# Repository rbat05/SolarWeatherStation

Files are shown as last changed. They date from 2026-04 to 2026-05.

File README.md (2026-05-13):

# SolarWeatherStation
An end-to-end, off-grid IoT environmental telemetry system featuring custom hardware, low-power RF bridging, and a retro LCD-themed web dashboard.









<p align="center">
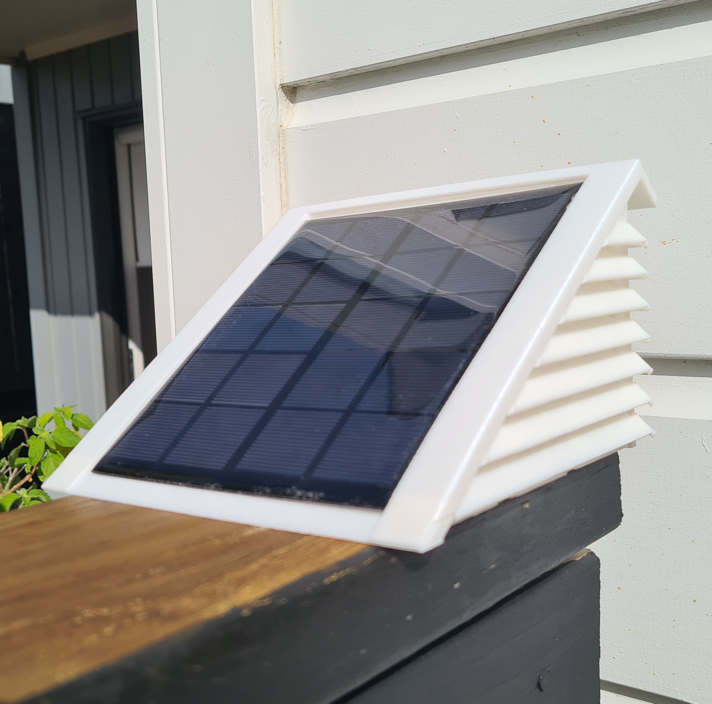
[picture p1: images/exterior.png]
Solar Weather Station Exterior
  
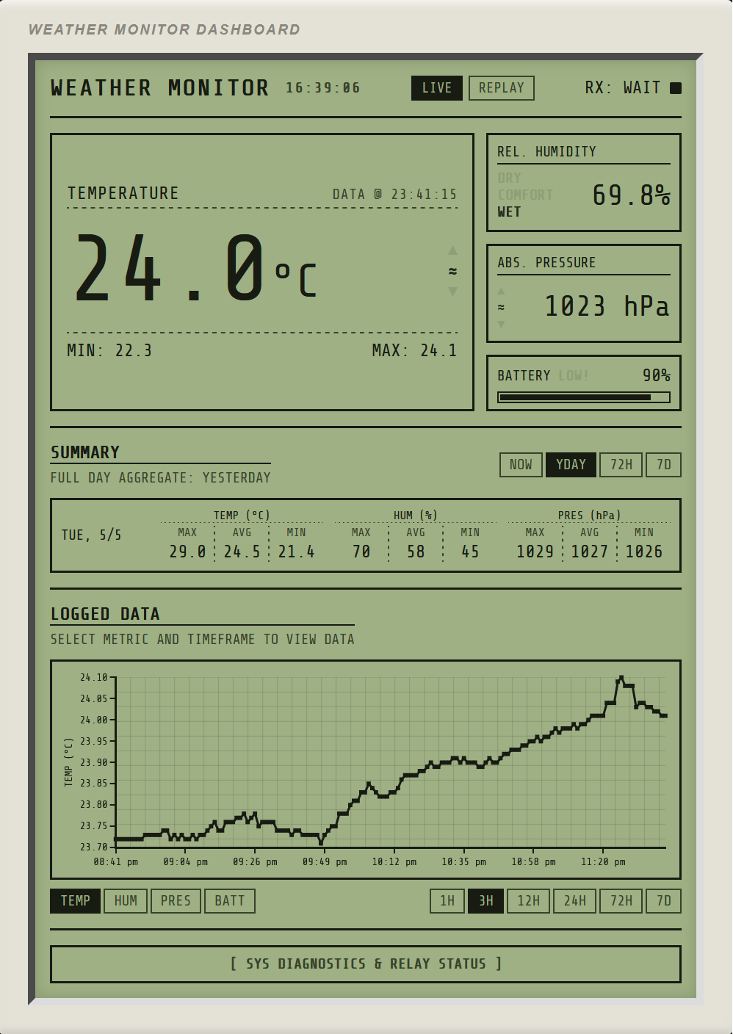
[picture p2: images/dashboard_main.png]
Solar Weather Station Dashboard
  <br>
  <em>Solar Weather Station Exterior (left) and Dashboard (right)</em>
</p>

## Table of Contents

1. [Overview](#overview)
2. [Features](#features)
3. [Performance](#performance)
4. [Design Showcase](#design-showcase)
5. [Bill of Materials](#bill-of-materials)
6. [System Architecture](#system-architecture)
7. [Firmware & Code](#firmware--code)
8. [3D-Printed Parts](#3d-printed-parts)
9. [License](#license)

---

## 1. Overview
The **Solar Weather Station** is a completely custom-engineered, three-tier IoT ecosystem designed to capture, transmit, and visualize highly accurate micro-climate data. 

>Currently measures **temperature**, **humidity**, **absolute pressure**, and **battery voltage** at 30 seconds intervals.

Operating entirely off-grid, the remote sensor node utilizes solar power and aggressive deep-sleep optimizations to monitor environmental conditions indefinitely. To bypass the extreme battery drain of standard WiFi, it broadcasts lightweight packets via ESP-NOW to a continuously powered indoor Relay node. This Relay acts as a bridge, forwarding the data into a local Python Flask server where it is logged, archived, and displayed on a visually striking, retro-commercial LCD-style dashboard.

## 2. Features
* **100% Off-Grid Operation:** Powered by a localized solar charging circuit and Li-Po battery.
* **Decoupled RF Architecture:** Uses a low-latency, low-power ESP-NOW to WiFi bridge, saving massive amounts of battery life compared to direct-to-router connections.
* **Bulletproof Failsafes:** Features hardware brownout bypassing, local SD card data logging, offline memory buffering (RTC memory), and relay rate-limited backfilling so data is never lost during network dropouts.
* **Retro LCD Dashboard:** A beautiful, responsive, bespoke green-and-black dot-matrix web interface built with pure HTML/JS, Flask, and SQLite.
* **Historical Replay Engine:** A dual-database architecture allows you to dynamically load archived CSV data into a sandbox database to "replay" historical weather events on the dashboard without interrupting the live data stream.
* **Local vs. Regional Analytics:** Automatically fetches regional telemetry from the Open-Meteo API to compare your micro-climate directly against metropolitan averages.

## 3. Performance
Aggressive power-saving techniques were implemented in the ESP32 C++ firmware. By throttling the clock speed down to 80MHz, actively forcing the WiFi/Bluetooth modems off during boot initialization, and removing parasitic hardware LEDs (like the one on the DS3231 RTC), the remote station achieves incredible efficiency:

* **Average Active Time:** < 8.0 seconds per wake cycle.
* **Average Active Current:** ~60 mA (Peak during SD Write & ESP-NOW transmission).
* **Average Sleep Current:** ~2.5 mA.
* **Weighted Average Draw:** ~4.03 mA over a standard cycle.

This ultra-low consumption allows the station to easily survive extended periods of heavy cloud cover without dropping below critical battery voltages.

## 4. Design Showcase

- **Mechanical Design:** Custom 3D-printed Stevenson Screen with integrated mounting points for the PCB and solar panel. The solar panel sits at a 35-degree angle to maximize sun exposure (in Auckland, NZ) while the louvers provide airflow to ensure accurate sensor readings.
  <p align="center">
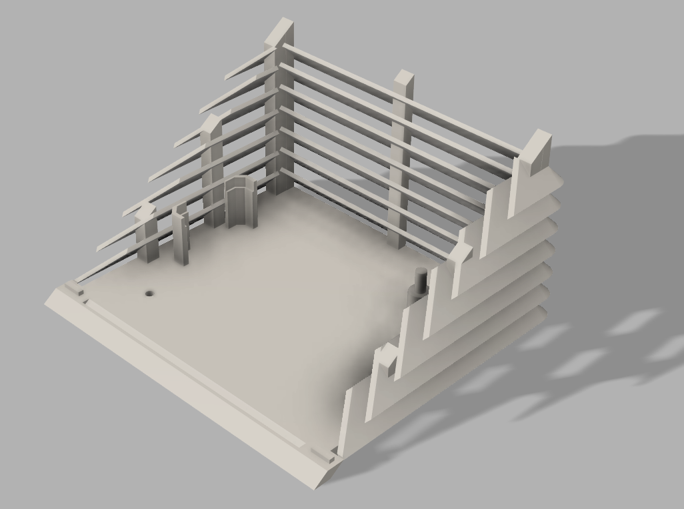
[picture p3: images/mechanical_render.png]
Mechanical Render
    <br>
    <em>3D-Printed Stevenson Screen Render</em>
  </p>

- **Internal Assembly:** Custom PCB secured inside the Stevenson Screen.
  <p align="center">
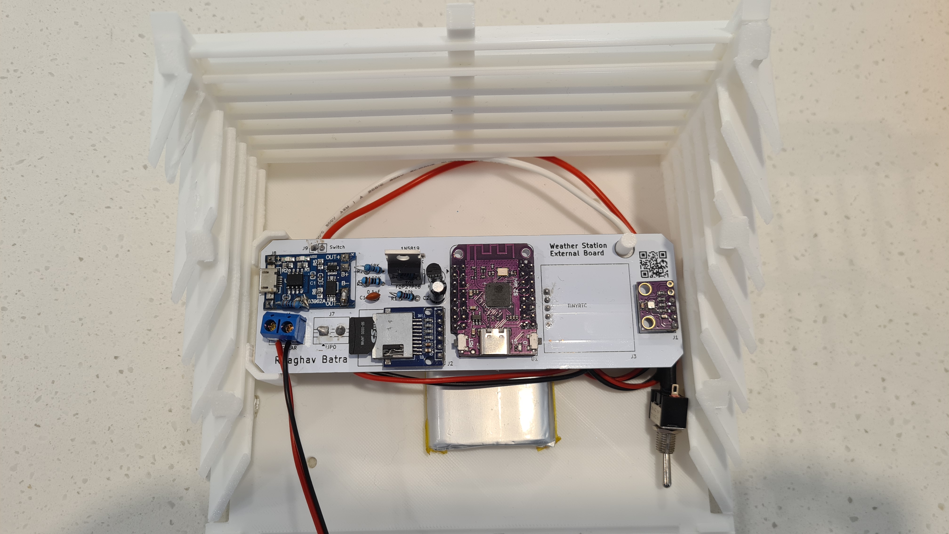
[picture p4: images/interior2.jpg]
Solar Weather Station Interior
    <br>
    <em>Custom PCB Mounted Inside Enclosure</em>
  </p>

- **LCD Dashboard:** A retro-inspired web interface displaying real-time and historical weather data.

**Dashboard Features:**

- **Live Mode:** Continuously streams real-time environmental data directly from the local SQLite database.
  <p align="center">
    Dashboard Main View (Live Mode)<br>
    <em>Main Dashboard View (Live Mode)</em>
  </p>

- **Historical Replay Engine:** Dynamically loads archived 7-day CSV files into a sandbox database to replay historical weather events without interrupting live data ingestion. Can set custom timeframes to analyze specific events (e.g., a storm).
  <p align="center">
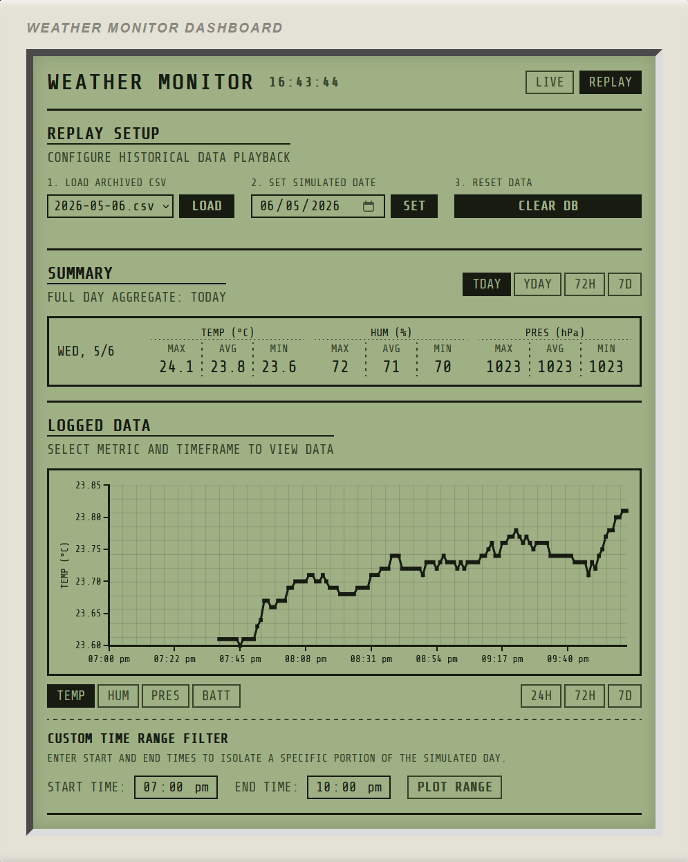
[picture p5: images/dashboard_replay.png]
Dashboard Replay Mode
    <br>
    <em>Replaying Historical Sandbox Data</em>
  </p>

- **Local vs. Regional Comparison:** Automatically polls regional telemetry from the Open-Meteo API to compare your micro-climate directly against metropolitan averages (displayed alongside the "Today" summary).
  <p align="center">
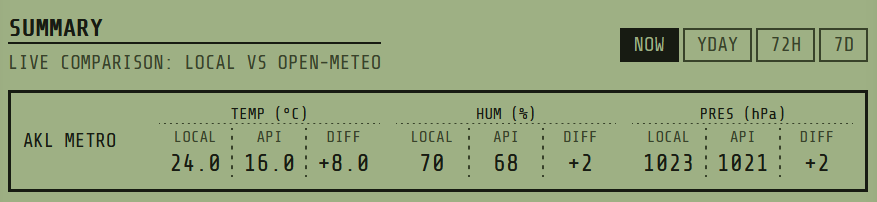
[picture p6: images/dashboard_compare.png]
Dashboard Regional Compare
    <br>
    <em>Local Micro-climate vs. Regional Averages</em>
  </p>

- **Summary Statistics:** Provides actionable insights and rolling statistics (High, Low, Average) across different timeframes:
  - **Today:** Current day metrics.
  - **Yesterday:** A rolling 24-hour window to spot diurnal patterns.
  - **72 Hours & 7 Days:** Extended views to analyze multi-day weather events and trends.

- **Interactive Graphing:** Powered by Chart.js, the interactive graph can map individual metrics over adjustable time-scales (1 hour, 3 hours, 12 hours, 24 hours, 72 hours, or 7 days):
  - **Temperature**
  - **Humidity**
  - **Absolute Pressure**
  - **Battery Voltage**
  <p align="center">
    Dashboard 7-Day Graph<br>
    <em>Interactive 7-Day Telemetry Chart</em>
  </p>

## 5. Bill of Materials
### Remote Weather Station
* **Microcontroller:** ESP32 (Throttled to 80MHz)
* **Environmental Sensor:** BME280 (Temperature, Humidity, Absolute Pressure)
* **Real-Time Clock:** DS3231 (Hardware power LED physically removed for power savings)
* **Storage:** MicroSD Card Module (SPI)
* **Power:** Solar Panel, TP4056 (or equivalent) Charge Controller, 3.7v Li-Po/18650 Battery

### Indoor Relay Node
* **Microcontroller:** ESP8266

### Local Server
* **Hardware:** Any local machine (e.g., Raspberry Pi) capable of running Python 3.

## 6. System Architecture
The system is broken into three distinct operational layers:

1. **Layer 1: Edge Telemetry (Weather Station)** 
   Wakes up on an interval timer, samples the BME280 and battery voltage, writes to the local SD card, and fires a rapid ESP-NOW string to the Relay before returning to deep sleep. For a detailed breakdown, see the [Weather Station README](./code/WeatherStationCode/README.md).
2. **Layer 2: Network Bridge (Relay Node)** 
   Stays awake permanently on mains power. Listens for the ESP-NOW MAC address. Upon receiving a packet, it formats it into a JSON payload and executes an HTTP POST request over the home WiFi network. For a detailed breakdown, see the [Relay Node README](./code/RelayCode/README.md).
3. **Layer 3: Data Ingestion & Visualization (Dashboard)** 
   A Python Flask server operating on a local machine. It intercepts the HTTP POST at the `/ingest` endpoint, commits the data to an SQLite database, handles infinite 7-day auto-archiving to CSV, and serves the UI. For a detailed breakdown, see the [Dashboard README](./code/DashboardCode/README.md).

## 7. Firmware & Code
The codebase is heavily modularized across three main directories. Please refer to their individual `README.md` files for deep dives into their logic.

* **`/code/WeatherStationCode`:** 
  C++ (PlatformIO) for the remote ESP32. Handles aggressive power management, hardware watchdog failsafes, I2C/SPI bus management, and RTC memory buffering.
* **`/code/RelayCode`:** 
  C++ (PlatformIO) for the indoor ESP8266. Features a non-blocking `millis()` architecture, in-memory offline packet buffering, auto-WiFi reconnections, and OTA flashing support.
* **`/code/DashboardCode`:** 
  Python/Flask backend and HTML/JS frontend. Handles the API endpoints, Open-Meteo polling, database querying, and the retro Chart.js interactive graph rendering.

## 8. Custom Hardware Integration
### Custom PCB (`/pcb`)
Rather than relying on messy jumper wires and breadboards, the Weather Station relies on a completely custom-designed Printed Circuit Board. This custom PCB integrates the ESP32, charge controllers, and sensor headers into a single, reliable footprint. This minimizes point-of-failure wire disconnects, reduces electrical noise on the I2C/SPI busses, and provides a perfectly dimensioned mounting solution for the 3D-printed case. Designed using KiCAD 10.

### 3D-Printed Parts (`/cad`)
All physical enclosures for the project were custom modeled in CAD to fit the bespoke electronics and withstand the elements.

* **Stevenson Screen (Weather Station):** 
  A classic multi-louvered meteorological enclosure. It is specifically designed to shield the BME280 sensor from direct UV radiation and precipitation while allowing ambient wind/air to freely pass through. This prevents artificial greenhouse heating inside the case, ensuring the temperature readings are a true reflection of the outside air. Provided a .step file for easy modification of the full assembly in any CAD software.
* **Low-Profile Relay Case:** 
  This enclosure can be found at [Makerworld](https://makerworld.com/en/models/58547-nodemcu-v2-cp2102-cover#profileId-60347). Credit to Lyron for the original design. A hole was cut on the top for the heatsink.

## 9. License
This project is licensed under the GNU General Public License v3.0 (GPL-3.0).

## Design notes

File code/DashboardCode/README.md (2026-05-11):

# Solar Weather Station - Dashboard

## Overview
The Dashboard code provides a visually striking, Retro Commercial LCD-themed web interface and a robust Python Flask backend to serve as the central hub for your Solar Weather Station. It receives incoming telemetry via HTTP POST, stores the data locally in an SQLite database, archives historical readings, and presents everything in a highly interactive, at-a-glance format.

## Features & Functions
*   **Flask Web Server & API:** Listens on `/ingest` for JSON or CSV formatted POST requests sent by the Relay node, validating and parsing the payload.
*   **Dual-Database Architecture:** Maintains a `weather.db` for live operational data and a separate `replay.db` for isolated historical analysis, ensuring the live data stream is never interrupted.
*   **Auto-Archival System:** Automatically prunes live database entries older than 7 days to prevent bloat, appending all raw incoming data to permanent daily `.csv` files inside the `archive` directory.
*   **External API Integration:** Fetches comparative weather metrics in real-time from the Open-Meteo API (Auckland Metro) to provide a local vs. regional analysis.

## Code Outcome
A complete, self-hosted web dashboard that requires no external cloud services to operate. It provides deep analytical tools for micro-climate data while maintaining a uniquely stylized, immersive user experience.

## Usability & Dashboard Interface

The dashboard is designed entirely around an aesthetic "Commercial Dot-Matrix LCD" theme. It prioritizes clarity, high contrast, and at-a-glance readability using a bespoke green-and-black color palette.

### Operational Modes
*   **LIVE Mode:** The default, real-time state. The dashboard automatically polls the backend every 5 seconds, pulling the absolute latest data. The UI displays real-time health badges (`RX: OK` or `RX: WAIT`) and updates the hero readouts instantaneously when the relay pushes a new packet.
*   **REPLAY Mode:** A powerful historical analysis tool. The user can select any archived `.csv` file from a dropdown, load it into the temporary replay database, and set a simulated date. The entire dashboard behaves as if that historical day is currently happening, allowing for deep-dive investigations into past weather events using a Custom Time Range filter.

### Displayed Metrics & Readouts
*   **Hero Readouts:**
    *   **Temperature (°C):** Features a massive digital readout with trend indicators (▲/≈/▼) showing if the temperature is rising, falling, or stable compared to the last hour. Includes daily Min/Max values.
    *   **Relative Humidity (%):** Includes visual segment thresholds indicating whether the air is `DRY` (<40%), `COMFORT` (40%-60%), or `WET` (>60%).
    *   **Absolute Pressure (hPa):** Monitors barometric pressure with rapid change indicators to help predict incoming weather fronts.
    *   **Battery Level (%):** A visual fill-bar representing the remote solar station's Li-Po battery charge, including a flashing `LOW!` warning segment if it drops below 20%.

### Interactive Charting
Powered by Chart.js, the main graph renders a strict dot-matrix style line chart (using straight lines and square points) with an animated radar-sweep effect sweeping across the canvas.
*   **Timeframes:** Users can pivot between 1H, 3H, 12H, 24H, 72H, and 7D views.
*   **Dynamic Gap Visualization:** If the weather station goes offline, the chart mathematically detects the missing time buckets. Instead of connecting unrelated data points, it seamlessly breaks the solid line, rendering a transparent, dashed "gap" line so the user knows exactly when data was lost.

### Summaries & Diagnostics
*   **Live Comparison:** The summary panel displays a side-by-side table comparing the local station's data directly against the regional Open-Meteo API, calculating the exact numerical difference.
*   **Aggregate Data:** Users can tab through yesterday, the last 3 days, and the last 7 days to view automatically calculated Highs, Lows, and Averages across all metrics.
*   **System Diagnostics Panel:** A collapsible menu dedicated to hardware health. It displays the timestamp of the last contact, raw payload strings, HTTP response codes, total packets received, and a calculated Packet Loss percentage.

### Deploy Folder
Inside the `deploy` folder, there is a static version of the dashboard that is used to showcase basic capabilties. To run this, change directory into the folder and start a simple HTTP server:
```bash
cd deploy
python3 -m http.server 8000
```
Then navigate to `http://localhost:8000` in your web browser to view the static dashboard.

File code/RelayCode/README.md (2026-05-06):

# Solar Weather Station - Relay Node

## Overview
The Relay code acts as the crucial bridge between the remote, low-power Weather Station and the centralized Server/Dashboard. Running on an ESP8266, it sits within the range of both the station's low-power radio (ESP-NOW) and the home's high-power WiFi network.

## Features & Functions
*   **Continuous Listening:** Operates completely awake, utilizing ESP-NOW to constantly listen for incoming, transient data packets broadcasted by the remote weather station.
*   **WiFi Forwarding:** Establishes and maintains a connection to the local WiFi network, taking the incoming ESP-NOW string and forwarding it to the Dashboard's `/ingest` API endpoint via HTTP POST requests.
*   **Health Dashboard Server:** Hosts a lightweight web server on port 80 displaying real-time diagnostics, including uptime, WiFi RSSI, rolling packet loss percentage, and offline buffer status.
*   **Over-The-Air (OTA) Updates:** Supports wireless flashing, allowing you to update the relay's firmware remotely without needing to physically disconnect it.

## Code Outcome
By decoupling the remote station from the local WiFi network, the Relay allows the station to save massive amounts of battery. The Relay guarantees data packets are successfully transitioned from off-grid radio signals to standard web traffic.

## Hardware & Software Safety Features
Because the Relay serves as a single point of failure for data ingestion, it includes robust fault-tolerance mechanisms:

1.  **Offline Buffering:** If the home WiFi drops or the backend Flask server restarts, the Relay does not discard incoming data. It stores up to 100 missed packets in an in-memory string array buffer.
2.  **Rate-Limited Backfill:** Once the server connection is re-established, the Relay pushes the buffered backlog using a rate-limited retry interval (e.g., 5 seconds) to prevent overwhelming the server with a massive burst of HTTP requests.
3.  **Non-Blocking Architecture:** Uses `millis()`-based timing instead of `delay()` for all primary loop operations. This ensures that a stalled HTTP request or a slow WiFi reconnection attempt never blocks the ESP-NOW callback, guaranteeing it never misses a radio packet from the outdoor station.
4.  **Auto-Reconnection:** Built-in WiFi fallback routines automatically negotiate reconnections if the primary network drops out.

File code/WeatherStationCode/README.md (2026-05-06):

# Solar Weather Station - Remote Node

## Overview
The Weather Station code powers the remote, solar-charged ESP32 microcontroller unit responsible for capturing local environmental telemetry. Its primary goal is to operate entirely off-grid, efficiently managing its own power reserves while providing highly accurate, continuous weather data via a BME280 sensor, DS3231 RTC, and local SD card storage.

## Features & Functions
*   **Environmental Telemetry:** Interfaces with a BME280 sensor via custom I2C pins (SDA: 33, SCL: 35) to capture Temperature, Relative Humidity, and Absolute Pressure. The sensor is kept in a low-power "sleep mode" and briefly awoken into "forced mode" just long enough to capture a reading.
*   **Aggressive Power Management:** The ESP32's clock speed is heavily throttled down from 240MHz to 80MHz, and the WiFi/Bluetooth modems are actively forced asleep during boot (`esp32ModemSleep()`) to aggressively shave off milli-amps during the active cycle.
*   **Deep Sleep Cycling:** To conserve battery, the station wakes up every 30 seconds, takes rapid readings, writes to the SD card, transmits the data packet via ESP-NOW, and immediately returns to a low-power deep sleep state. Active time is kept to an absolute minimum (under 8 seconds).
*   **Local SD Card Archival:** Every reading is appended to a local CSV file on an SD card via a custom SPI bus (SCK: 7, MISO: 9, MOSI: 11, CS: 12). If wireless transmission fails, the physical data is completely secure.
*   **RTC Memory Buffering:** The code utilizes the ESP32's `RTC_DATA_ATTR` memory to maintain an offline buffer of up to 10 readings across deep sleep cycles. If the Relay node is unreachable, the station stores the readings and bulk-sends the backlog (oldest first) on the next successful connection.

## Code Outcome
A highly resilient, "deploy-and-forget" weather node that can run indefinitely on solar power, constantly delivering localized weather patterns without human intervention.

## Hardware & Software Safety Features
Because this node is deployed remotely and exposed to the elements, several safety mechanisms have been implemented in the code:

1.  **Manual Brownout Override:** Standard ESP32 hardware brownout detection can sometimes trigger false-positive boot loops on solar setups when the voltage slightly dips during radio spikes. The code intentionally bypasses the internal hardware check (`WRITE_PERI_REG(RTC_CNTL_BROWN_OUT_REG, 0)`) to ensure the board successfully boots and delegates battery management directly to the firmware logic.
2.  **Infinite Loop Safety Catch:** A failsafe `loopCounter` mechanism exists in the main `loop()` function. Because the execution is entirely handled sequentially in `setup()`, if the main loop accidentally iterates more than 1,000 times, the code mathematically determines the microcontroller is hung/frozen and forcefully throws it back into deep sleep to prevent battery drain.
3.  **Offline Resilience:** The combination of local SD storage and the 10-packet `RTC_DATA_ATTR` buffer ensures that brief networking dropouts, relay reboots, or WiFi outages do not result in permanent data loss. 
4.  **Visual Debugging:** Pin 15 provides physical LED flashes upon boot initialization and successful cycle completion, allowing for on-site visual confirmation of the unit's health without connecting it to a computer.

## Power Consumption & Hardware Notes
Based on a typical solar-assisted Li-Po setup, the system is highly optimized:
*   **Average Active Current:** ~60 mA (including SD write and ESP-NOW WiFi spikes).
*   **Average Sleep Current:** ~2.5 mA.
*   **Weighted Draw:** ~4.03 mA average over a cycle.

**⚠️ CRITICAL HARDWARE WARNING:** 
The DS3231 RTC module contains a surface-mounted power LED. Because the DS3231 is kept constantly powered, this LED single-handedly draws almost as much current as the sleeping ESP32! To achieve proper multi-month battery life, the power LED on the DS3231 breakout board *must* be physically desoldered or destroyed.

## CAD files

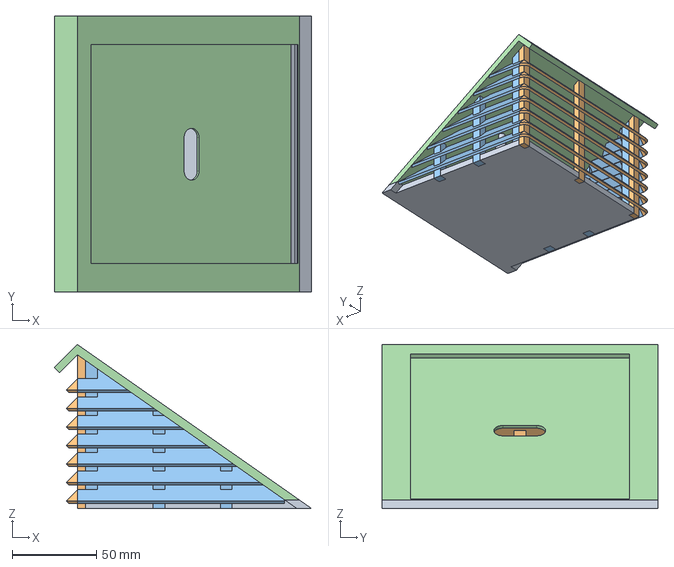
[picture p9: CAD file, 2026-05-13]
cad/external_unit_mini.step
152.9 x 164.0 x 97.5 mm

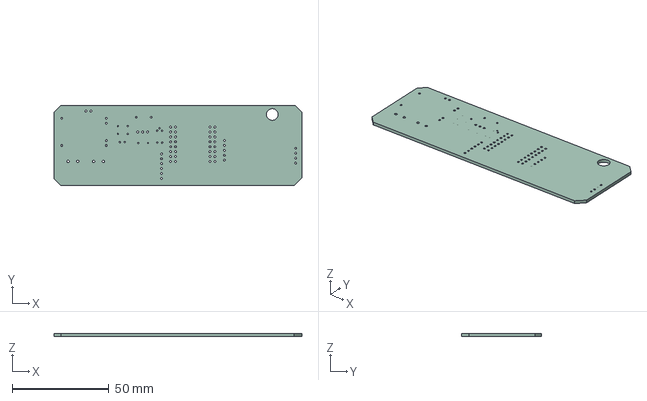
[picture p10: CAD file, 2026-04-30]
pcb/weather_station_ext/pcb.step
128.0 x 41.5 x 1.51 mm

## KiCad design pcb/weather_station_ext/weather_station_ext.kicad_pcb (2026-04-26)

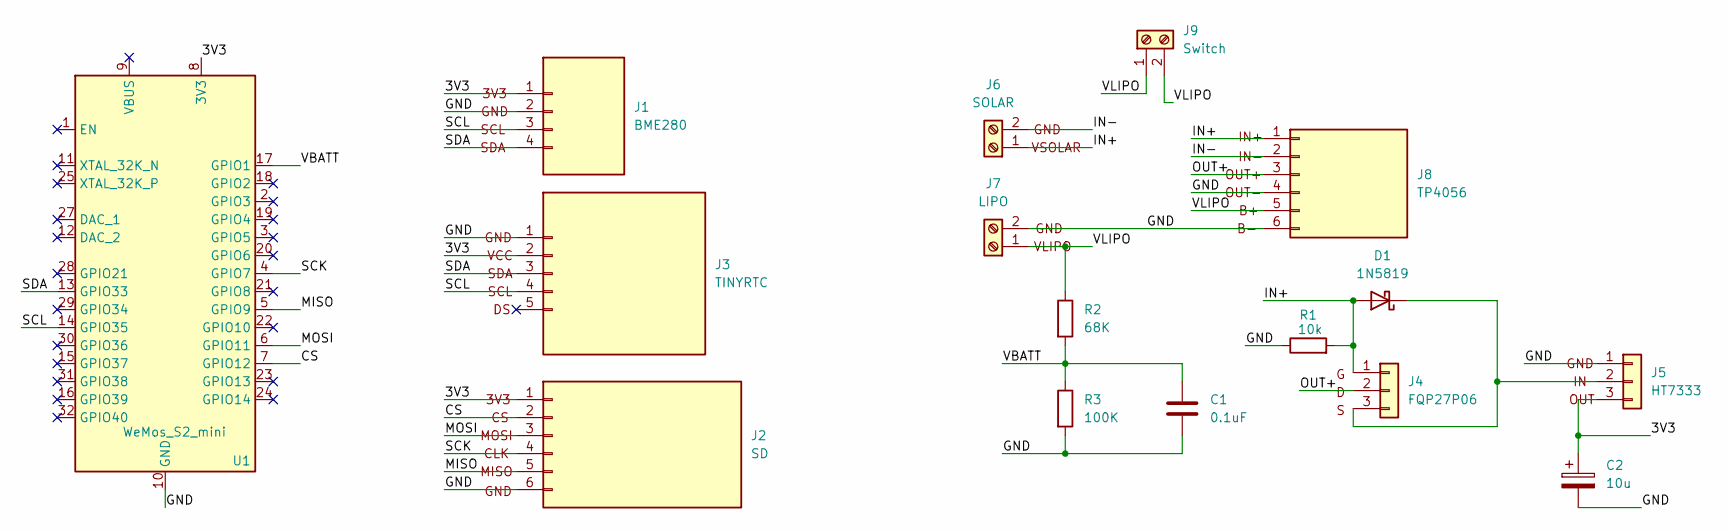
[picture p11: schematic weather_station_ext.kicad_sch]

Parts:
C1: 0.1uF; C_Disc_D3.0mm_W1.6mm_P2.50mm
C2: 10u; C_Disc_D3.0mm_W1.6mm_P2.50mm
D1: 1N5819; D_A-405_P7.62mm_Horizontal
J1: BME280; PinSocket_1x04_P2.54mm_Vertical
J2: SD; PinSocket_1x06_P2.54mm_Vertical
J3: TINYRTC; PinSocket_1x05_P2.54mm_Vertical
J4: FQP27P06; TO-220-3_Vertical
J5: HT7333; TO-92
J6: SOLAR; TerminalBlock_MaiXu_MX126-5.0-02P_1x02_P5.00mm
J7: LIPO; TerminalBlock_MaiXu_MX126-5.0-02P_1x02_P5.00mm
J8: TP4056; PinHeader_1x06_P2.54mm_Vertical
J9: Switch; PinHeader_1x02_P2.54mm_Vertical
R1: 10k; R_Axial_DIN0204_L3.6mm_D1.6mm_P5.08mm_Vertical
R2: 68K; R_Axial_DIN0204_L3.6mm_D1.6mm_P5.08mm_Vertical
R3: 100K; R_Axial_DIN0204_L3.6mm_D1.6mm_P5.08mm_Vertical
U1: WeMos_S2_mini; wemoss2

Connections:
/3V3: C2.1, J1.1 (3V3), J2.1 (3V3), J3.2 (3V3), J5.3 (OUT), U1.8 (3V3)
/CS: J2.2 (CS), U1.7 (GPIO12)
/GND: C1.2, C2.2, J1.2 (GND), J2.6 (GND), J3.1 (GND), J5.1 (GND), J7.2 (GND), J8.4 (OUT-), J8.6 (B-), R1.1, R3.2, U1.10 (GND), U1.26 (GND)
/IN+: D1.2 (A), J4.1 (GATE), J6.1 (VSOLAR), J8.1 (IN+), R1.2
/IN-: J6.2 (GND), J8.2 (IN-)
/MISO: J2.5 (MISO), U1.5 (GPIO9)
/MOSI: J2.3 (MOSI), U1.6 (GPIO11)
/OUT+: J4.2 (DRAIN), J8.3 (OUT+)
/SCK: J2.4 (CLK), U1.4 (GPIO7)
/SCL: J1.3 (SCL), J3.4 (SCL), U1.14 (GPIO35)
/SDA: J1.4 (SDA), J3.3 (SDA), U1.13 (GPIO33)
/VBATT: C1.1, R2.2, R3.1, U1.17 (GPIO1)
/VLIPO: J7.1 (VLIPO), J8.5 (B+), J9.1 (VLIPO), J9.2 (VLIPO), R2.1
unnamed: D1.1 (K), J4.3 (SOURCE), J5.2 (IN)

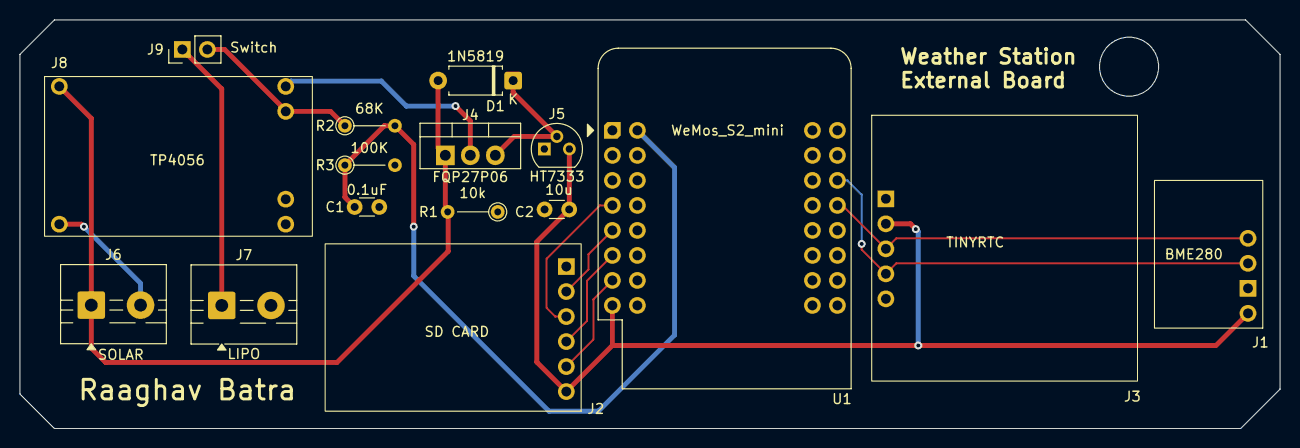
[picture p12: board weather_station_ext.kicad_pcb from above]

Board: 2 copper layers, 128.0 x 41.5 mm, 16 parts (0 on the bottom side), 14 nets.

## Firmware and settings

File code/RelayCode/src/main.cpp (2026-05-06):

#include <Arduino.h>
#include <ArduinoOTA.h>
#include <ESP8266HTTPClient.h>
#include <ESP8266WebServer.h>
#include <ESP8266WiFi.h>
#include <WiFiClient.h>
#include <espnow.h>
#include <user_interface.h>

#include "config.hpp"

volatile bool dataReceived = false;
String incomingDataString = "";

// Health Server & Buffer Variables
ESP8266WebServer server(80);
const int MAX_BUFFER_SIZE = 100;
String offlineBuffer[MAX_BUFFER_SIZE];
int bufferCount = 0;

unsigned long packetsReceived = 0;
int lastHttpResponse = 0;
unsigned long lastPostAttempt = 0;
unsigned long firstPacketTime = 0;
bool firstPacketReceived = false;
const unsigned long POST_RETRY_INTERVAL = 5000;

// --- UPDATE WITH YOUR COMPUTER IP ---
const char* serverName =
    "http://192.168.68.63:5000/ingest";  // Replaced /api/weather with /ingest

void handleRoot() {
  String html = "<!DOCTYPE html><html><head><title>Relay Health</title>";
  html +=
      "<meta name=\"viewport\" content=\"width=device-width, "
      "initial-scale=1\">";
  html +=
      "<style>body{font-family:Arial; margin:2rem; background-color:#121212; "
      "color:#ffffff;}";
  html +=
      ".stat{font-size:1.2rem; margin-bottom:10px; padding:10px; "
      "background:#1e1e1e; border-radius:5px;}</style></head><body>";
  html += "<h1>Weather Station Relay Health OTA TEST</h1>";

  unsigned long uptimeSeconds = millis() / 1000;
  int days = uptimeSeconds / 86400;
  int hours = (uptimeSeconds % 86400) / 3600;
  int mins = (uptimeSeconds % 3600) / 60;
  int secs = uptimeSeconds % 60;

  html += "<div class=\"stat\"><b>Uptime:</b> " + String(days) + "d " +
          String(hours) + "h " + String(mins) + "m " + String(secs) + "s</div>";
  html += "<div class=\"stat\"><b>WiFi RSSI:</b> " + String(WiFi.RSSI()) +
          " dBm</div>";
  html += "<div class=\"stat\"><b>WiFi Channel:</b> " + String(WiFi.channel()) +
          "</div>";
  html += "<div class=\"stat\"><b>ESP-NOW Packets Received:</b> " +
          String(packetsReceived) + "</div>";

  String lossStr = "--";
  if (firstPacketReceived) {
    unsigned long elapsedSec = (millis() - firstPacketTime) / 1000;
    unsigned long expected = (elapsedSec / 30) + 1;
    float loss = 100.0 * (1.0 - ((float)packetsReceived / expected));
    if (loss < 0) loss = 0;
    lossStr = String(loss, 1) + "% (" + String(expected) + " expected)";
  }
  html +=
      "<div class=\"stat\"><b>Rolling Packet Loss:</b> " + lossStr + "</div>";

  html += "<div class=\"stat\"><b>Latest ESP-NOW Packet:</b> " +
          (incomingDataString == "" ? "None" : incomingDataString) + "</div>";
  html += "<div class=\"stat\"><b>Last HTTP Response Code:</b> " +
          String(lastHttpResponse) + "</div>";
  html += "<div class=\"stat\"><b>Offline Buffer Status:</b> " +
          String(bufferCount) + " / " + String(MAX_BUFFER_SIZE) + "</div>";

  html += "</body></html>";
  server.send(200, "text/html", html);
}

// Callback function that will be executed when data is received
void onDataReceived(uint8_t* senderMac, uint8_t* incomingData, uint8_t len) {
  // Write the incoming data to the uint8_t array
  uint8_t recieved[len + 1];

  Serial.print("Received: ");

  for (int i = 0; i < len; i++) {
    Serial.print((char)incomingData[i]);
    recieved[i] = incomingData[i];
  }

  recieved[len] = '\0';

  // Convert the uint8_t array to a String
  incomingDataString = String((char*)recieved);
  dataReceived = true;
}

void setup() {
  Serial.begin(115200);
  Serial.println("\nStarting Relay...");

  // Set device as a Wi-Fi Station
  WiFi.mode(WIFI_AP_STA);
  WiFi.begin(ssid, password);

  while (WiFi.status() != WL_CONNECTED) {
    delay(1000);
    Serial.println("Connecting to Wi-Fi...");
  }

  Serial.print("Station IP Address: ");
  Serial.println(WiFi.localIP());
  Serial.print("Wi-Fi Channel: ");
  Serial.println(WiFi.channel());

  // Print MAC address of the receiver
  Serial.print("Receiver MAC: ");
  Serial.println(WiFi.macAddress());

  // Initialize ESP-NOW
  if (esp_now_init() != 0) {
    Serial.println("Error initializing ESP-NOW");
    return;
  }

  // Setup OTA
  ArduinoOTA.setHostname("Relay");
  ArduinoOTA.onStart([]() { Serial.println("\nStarting OTA update..."); });
  ArduinoOTA.onEnd([]() { Serial.println("\nOTA Update Complete!"); });
  ArduinoOTA.onProgress([](unsigned int progress, unsigned int total) {
    Serial.printf("Progress: %u%%\r", (progress / (total / 100)));
  });
  ArduinoOTA.onError([](ota_error_t error) {
    Serial.printf("Error[%u]: ", error);
    if (error == OTA_AUTH_ERROR)
      Serial.println("Auth Failed");
    else if (error == OTA_BEGIN_ERROR)
      Serial.println("Begin Failed");
    else if (error == OTA_CONNECT_ERROR)
      Serial.println("Connect Failed");
    else if (error == OTA_RECEIVE_ERROR)
      Serial.println("Receive Failed");
    else if (error == OTA_END_ERROR)
      Serial.println("End Failed");
  });
  ArduinoOTA.begin();

  // Setup Health Web Server
  server.on("/", handleRoot);
  server.begin();

  // Register callback for receiving data
  esp_now_set_self_role(ESP_NOW_ROLE_SLAVE);  // ESPNOW OLD
  esp_now_register_recv_cb(onDataReceived);

  Serial.println("Setup complete. Waiting for data...");
}

void loop() {
  // Handle OTA updates
  ArduinoOTA.handle();

  // Listen for incoming HTTP requests to the health dashboard
  server.handleClient();

  if (dataReceived == true) {
    packetsReceived++;

    if (!firstPacketReceived) {
      firstPacketReceived = true;
      firstPacketTime = millis();
    }

    // Store reading in the buffer
    if (bufferCount < MAX_BUFFER_SIZE) {
      offlineBuffer[bufferCount++] = incomingDataString;
    } else {
      // Buffer full: shift everything left (drop oldest) to make room for
      // newest
      for (int i = 1; i < MAX_BUFFER_SIZE; i++) {
        offlineBuffer[i - 1] = offlineBuffer[i];
      }
      offlineBuffer[MAX_BUFFER_SIZE - 1] = incomingDataString;
    }

    dataReceived = false;
    Serial.flush();
  }

  // If we have buffered data, try to send it (rate-limited to avoid spamming a
  // dead server)
  if (bufferCount > 0 && (millis() - lastPostAttempt > POST_RETRY_INTERVAL)) {
    if (WiFi.status() == WL_CONNECTED) {
      lastPostAttempt = millis();
      WiFiClient client;
      HTTPClient http;

      http.begin(client, serverName);
      http.addHeader("Content-Type", "text/plain");

      int httpResponseCode = http.POST(offlineBuffer[0]);
      lastHttpResponse = httpResponseCode;

      if (httpResponseCode > 0) {
        Serial.print("HTTP POST Success, Code: ");
        Serial.println(httpResponseCode);

        // Successfully reached server, remove from buffer
        for (int i = 1; i < bufferCount; i++) {
          offlineBuffer[i - 1] = offlineBuffer[i];
        }
        bufferCount--;

        // If success code, immediately trigger next loop to blast remaining
        // backlog
        if (httpResponseCode == 200 || httpResponseCode == 201)
          lastPostAttempt = 0;
      } else {
        Serial.print("HTTP POST Error: ");
        Serial.println(httpResponseCode);
      }
      http.end();
    } else {
      // If WiFi is disconnected, silently wait and try again later
    }
  }
}

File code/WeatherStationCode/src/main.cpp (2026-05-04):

#include <Arduino.h>  // Built-in library
#include <Wire.h>
#include <string.h>

#include <iostream>  // Built-in library

#include "bme280_temp_humi_pres.hpp"
#include "ds3231_rtc.hpp"
#include "espNOW_send.hpp"
#include "sd_write.hpp"
#include "utilities.hpp"

// Add this line to include the ESP32-specific header
#include "soc/rtc_cntl_reg.h"
#include "soc/soc.h"

// Custom I2C Pins
const int I2C_SDA = 33;
const int I2C_SCL = 35;

// BME280 - Connected via I2C
Adafruit_BME280 bme280;

// DS3231 RTC - Connected via I2C
RTC_DS3231 rtc;

// Battery Pin - Connected via Analog, G1 = Battery
const int BATTERY_PIN = 1;

// Program parameters
const int SLEEP_SECONDS = 30;    // Sleep for 30 seconds
const int ESP_CLOCK_SPEED = 80;  // Set clock speed to 80MHz

// Custom SPI Pins
const int SPI_SCK = 7;
const int SPI_MISO = 9;
const int SPI_MOSI = 11;
const int SD_CS_PIN = 12;  // Chip select pin for SD card

// LED Pin
const int LED = 15;

// Store up to 10 readings for ESP-NOW in RTC memory
RTC_DATA_ATTR char espNowBuffer[10][128];
RTC_DATA_ATTR int espNowBufferCount = 0;

void setup() {
  // Disable brownout detector, thug it out lil bro
  WRITE_PERI_REG(RTC_CNTL_BROWN_OUT_REG, 0);
  Serial.begin(115200);

  // Blink LED twice - signify program start
  pinMode(LED, OUTPUT);
  digitalWrite(LED, HIGH);
  delay(50);
  digitalWrite(LED, LOW);
  delay(50);
  digitalWrite(LED, HIGH);
  delay(50);
  digitalWrite(LED, LOW);
  delay(50);

  // Explicitly start I2C and SPI using our defined pins
  Wire.begin(I2C_SDA, I2C_SCL);
  SPI.begin(SPI_SCK, SPI_MISO, SPI_MOSI, SD_CS_PIN);

  printWakeupReason();

  bme280Setup(bme280);
  setupRTC(rtc);

  // ESP BT and Wifi off, clock speed 240MHz->80MHz
  esp32ModemSleep();
  esp32ClockSpeedChange(ESP_CLOCK_SPEED);

  // BME280 into forced mode to take readings
  bme280ForcedMode();

  float temperature = bme280GetTemperature(bme280);
  float humidity = bme280GetHumidity(bme280);
  float pressure = bme280GetPressure(bme280);

  // BME280 into sleep mode after readings taken
  bme280SleepMode();

  // Serial.print("Temperature: " + String(temperature) + "°C ");
  // Serial.print("Humidity: " + String(humidity) + "% ");
  // Serial.println("Pressure: " + String(pressure) + "hPa");

  String timestamp = getTimestamp(rtc);
  // Serial.println("Timestamp: " + timestamp);

  BatteryInfo battery_info = getBatteryInfo(BATTERY_PIN);
  // Serial.print("Battery Voltage: " + String(battery_info.voltage) + "V ");
  // Serial.println("Battery Percentage: " + String(battery_info.percentage) +
  //                "%");

  String filename = getFilename(rtc);
  // Serial.println("Filename: " + filename);

  // Create a data struct to hold all the readings
  Readings data;
  data.dateTime = timestamp;
  data.temperature = temperature;
  data.humidity = humidity;
  data.pressure = pressure;
  data.batteryVoltage = battery_info.voltage;
  data.batteryPercentage = battery_info.percentage;

  // Get string representation of the data, and write data to SD
  String formattedData = sdWriteReadings(data, filename);

  // 1. Add current reading to ESP-NOW buffer
  if (espNowBufferCount < 10) {
    strncpy(espNowBuffer[espNowBufferCount], formattedData.c_str(), 127);
    espNowBuffer[espNowBufferCount][127] = '\0';
    espNowBufferCount++;
  } else {
    // Buffer is full: shift old readings out to make room for newest one
    for (int i = 1; i < 10; i++) {
      strncpy(espNowBuffer[i - 1], espNowBuffer[i], 128);
    }
    strncpy(espNowBuffer[9], formattedData.c_str(), 127);
    espNowBuffer[9][127] = '\0';
  }

  // 2. Try sending everything in the buffer (oldest first)
  int successfulSends = 0;
  for (int i = 0; i < espNowBufferCount; i++) {
    if (sendData(String(espNowBuffer[i]))) {
      successfulSends++;
    } else {
      break;  // Stop on first failure, leave rest in buffer for next cycle
    }
  }

  // 3. Remove successful sends from buffer
  if (successfulSends > 0) {
    int remaining = espNowBufferCount - successfulSends;
    for (int i = 0; i < remaining; i++) {
      strncpy(espNowBuffer[i], espNowBuffer[i + successfulSends], 128);
    }
    espNowBufferCount = remaining;
  }

  // Clear the serial buffer, turn off modems
  Serial.flush();
  esp32ModemSleep();

  // Blink LED twice - signify program end
  digitalWrite(LED, HIGH);
  delay(50);
  digitalWrite(LED, LOW);
  delay(50);
  digitalWrite(LED, HIGH);
  delay(50);
  digitalWrite(LED, LOW);
  delay(50);

  // Go to sleep for 30sec
  // Serial.println("Going to sleep now.");
  esp32DeepSleep(SLEEP_SECONDS);
}

int loopCounter = 0;

// Safety catch loop
void loop() {
  loopCounter++;
  if (loopCounter >= 1000) {
    // Serial.println(
    //     "Safety catch triggered: Trapped in loop, forcing deep sleep!");
    esp32DeepSleep(SLEEP_SECONDS);
  }
  delay(10);  // Prevent watchdog timeout while looping
}

/*
 * Power Consumption & Battery Life Estimate
 * ---------------------------------------
 * Based on a 5-minute (300s) deep sleep cycle and a 4000mAh LiPo battery.
 *
 * WARNING: The DS3231 module's power-on LED is a major power drain!
 *
 * 1. Active Mode: ~8.0 seconds per cycle
 *    - Average Active Current: ~60 mA (includes SD write and ESP-NOW WiFi
 * spikes)
 * 2. Deep Sleep Mode: ~292 seconds per cycle
 *    - Average Sleep Current: ~2.5 mA (0.5mA from SD module + 2.0mA from RTC
 * LED)
 *
 * Weighted Average Current: ~4.03 mA
 * Estimated Runtime (without solar): ~41 Days
 *
 * To achieve >2 months of battery life, the power LED on the DS3231 module
 * MUST be physically removed.
 */

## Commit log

2025-01-04 Created seperate files for different sensors.
2025-01-04 BME280 sensor setup and get values functions written.
2025-01-05 UV sensor functionality code written.
2025-02-04 Sampling battery voltage readings, shortened days. Modularised head unit code.
    [main.cpp, sd_read.cpp, utilities.cpp]
2025-02-07 Got rid of UV sensor code, sensor too unreliable. New data logging format, create new file daily. Code cleanup.
2025-02-08 Code cleanup. Weather station code finalised for current hardware. Head Unit needs webserver.
2025-02-10 Working webserver, ESPNOW comms, data logging. Implemented landing page with daily stats, updated everytime new reading is sent. Fixed brownout stability issues.
    [main.cpp, utilities.cpp]
2025-07-11 Readme update, added updated wiring diagram
2026-04-27 changed esp32 to s2 mini, confirmed working on external pcb.
2026-04-30 implemented safety features in case sd or sensor failure
    [pcb.step]
2026-05-04 made headunit be a relay to a server, removed all other func. added buffer to main station, if esp now fails
    [pcb.step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]
2026-05-04 added ota support, removed channel fixing in weather station
    [main.cpp]
2026-05-04 fixed esp now issues, station now sends data to relay, relay can handle http post and ota updates
    [main.cpp]
2026-05-09 created static showcase for dashboard
    [2026-05-03.csv, 2026-05-04.csv, 2026-05-05.csv]
2026-05-11 good to go showcase
    [2026-05-03.csv, 2026-05-04.csv, 2026-05-05.csv]
2026-05-13 readme updated with images. waiting for full day data run
    [external_unit_mini.step]

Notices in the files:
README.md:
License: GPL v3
